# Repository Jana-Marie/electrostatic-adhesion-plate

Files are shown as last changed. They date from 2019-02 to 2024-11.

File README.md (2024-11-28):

# electrostatic-adhesion-plate

#### Motivation

The motivation behind this project is that I wanted to test how strong [electro-adhesion](https://en.wikipedia.org/wiki/Electroadhesion) really is and what clamping force I can get myself with it. Since PCBs are very inexpensive nowadays, the choice fell on electrodes directly on a circuit board. In the first version (100x100mm) the electrode gap is not yet optimal and there are points where corona discharges are likely, this is fixed in the second version (DinA5).

A batch (50pcs) of the seccond version is about to be ordered by me.

#### Design

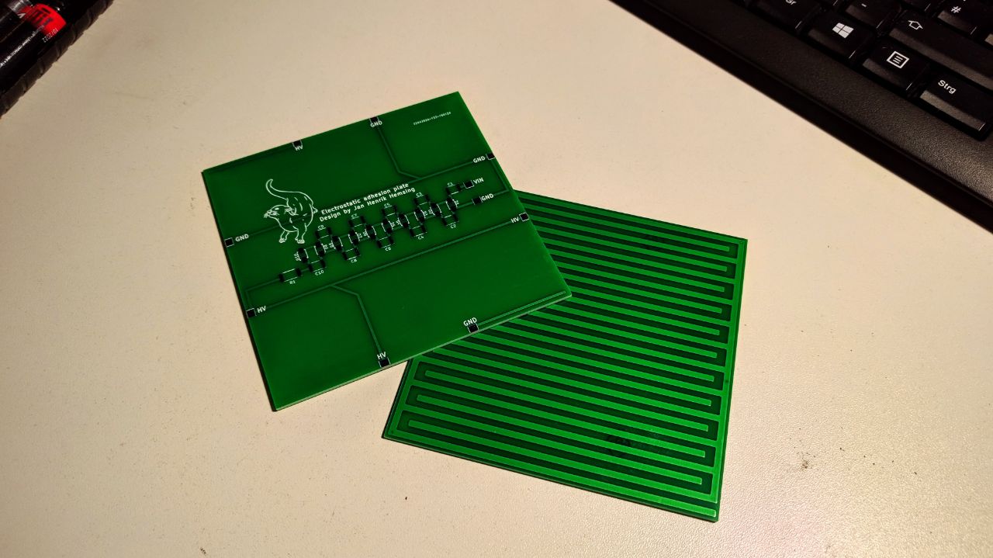
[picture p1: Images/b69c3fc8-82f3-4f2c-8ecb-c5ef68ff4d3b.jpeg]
Design


The boards were designed so that they can be connected to larger printed circuit boards (electrically) using solder connections. This makes it possible to build relatively large electroadhesive surfaces with relatively inexpensive printed circuit boards.

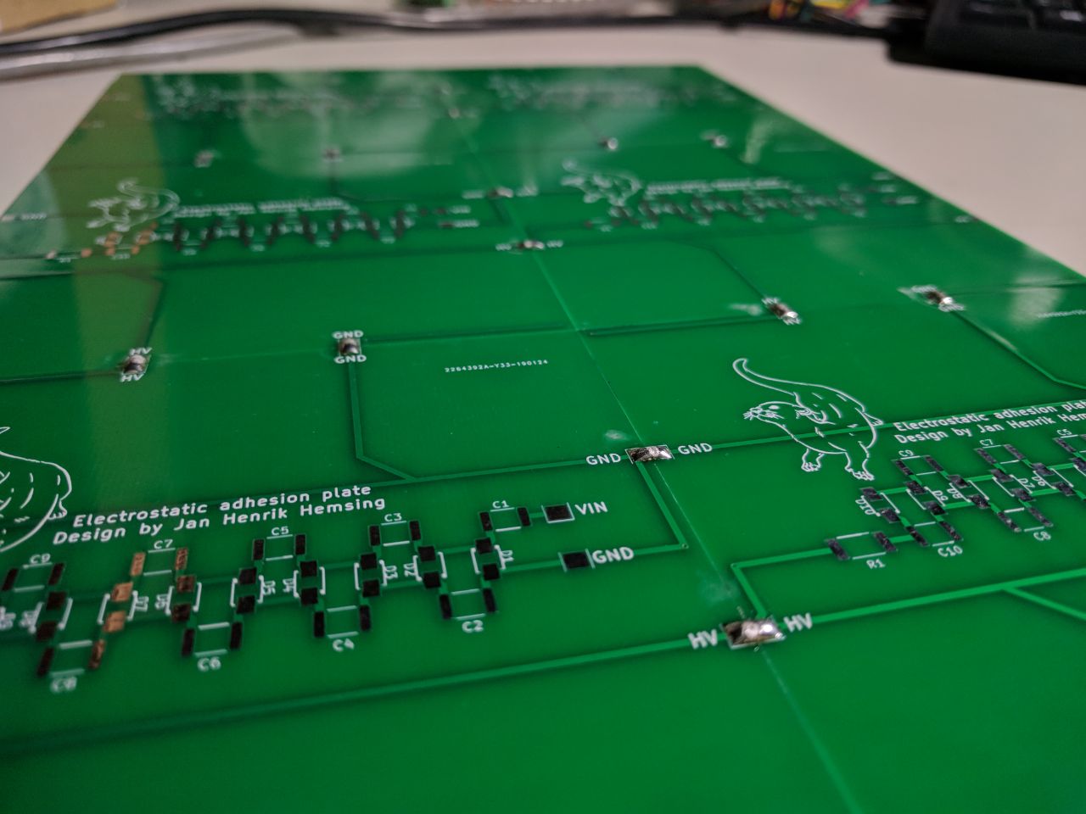
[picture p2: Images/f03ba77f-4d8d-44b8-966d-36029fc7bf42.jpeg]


The surface of each PCB or the whole panel should be coated with a high voltage isolator, as the soldermask does not withstand high voltage very well. Kapton is a suitable material as its dielectric strength is about 7.6kV/25µm, unfortunately it is difficult to apply.
Another solution which is being tested is PlastiDip. PlastiDip has a much lower dielectric strength 1.6kV/25µm, so it has to be applied thicker. The advantage here is the rubber-like surface which generates a higher shear force due to its friction.

https://github.com/user-attachments/assets/e9a8f286-f70a-4371-af7a-df20809293cf

https://github.com/user-attachments/assets/fc1b60f5-51d2-4803-b8a3-286581b4381b

The electrode voltage should be between 500V and 5kV DC (depending on the design), whereby a higher voltage means a higher holding force. This voltage can be obtained from any cheap DC high voltage source (e.g. a bug zapper) or from a low AC voltage source (Please do not use direct mains voltage). The AC voltage can be multiplied and rectified by the Cockcroft Walton voltage multiplier on the back of the PCB.

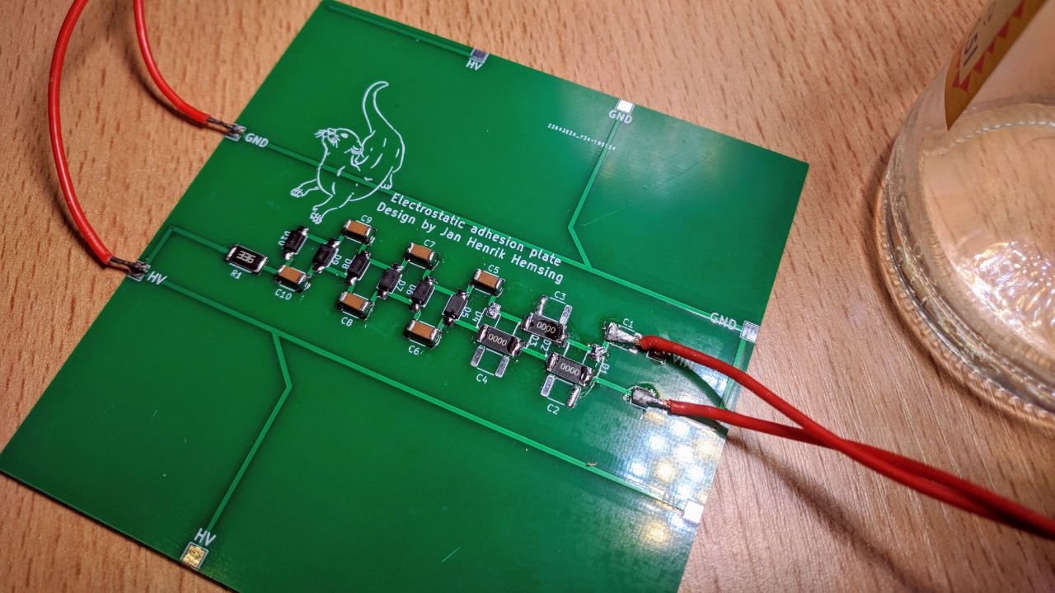
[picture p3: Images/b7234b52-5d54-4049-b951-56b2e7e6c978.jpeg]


___

## [100mm * 100mm](100100mm/)

| **Parameter** | **Value** |
| --- |:---:|
| Electrode Voltage | 500V-2000V |
| Electrode Voltage*| 500V-3000V |
| *Without extra coating (silkscreen)*|
| shearing force | 9N @1.4kV |
| shearing force cm²| 90mN/cm² @1.2kV|
| adhesive force | ** |
| **PlastiDip Coating** |
| shearing force | 4N @1.4kV |
| shearing force cm²| 40mN/cm² @1.2kV|
| adhesive force | ** |
| **Kapton Coating** |
| shearing force | 2.5N @1.4kV |
| shearing force cm²| 25mN/cm² @1.2kV|
| adhesive force | ** |

\* With Insulation

\** TBD

#### [Demo Video](https://twitter.com/_Jana_Marie/status/1094664006059593729)

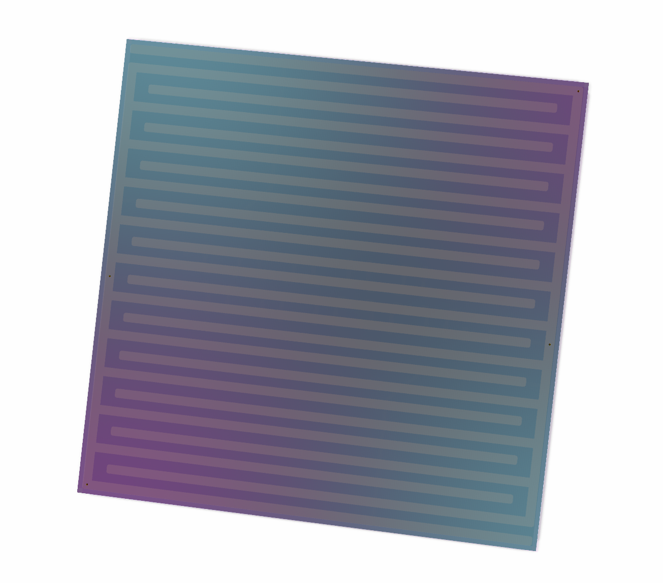
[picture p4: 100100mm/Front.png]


___

## [DIN A5](DINA5)

| **Parameter** | **Value** |
| --- |:---:|
| Electrode Voltage | 500V-2000V |
| Electrode Voltage*| 500V-5000V |
| shearing force | ** |
| adhesive force | ** |

\* With Insulation

\** TBD

#### Changes to V1 (100100mm)

 * Size is now 148*210mm (DinA5)
 * Electrode width and distance are optimized
 * M3 threads where added
 * Sharp edges where removed

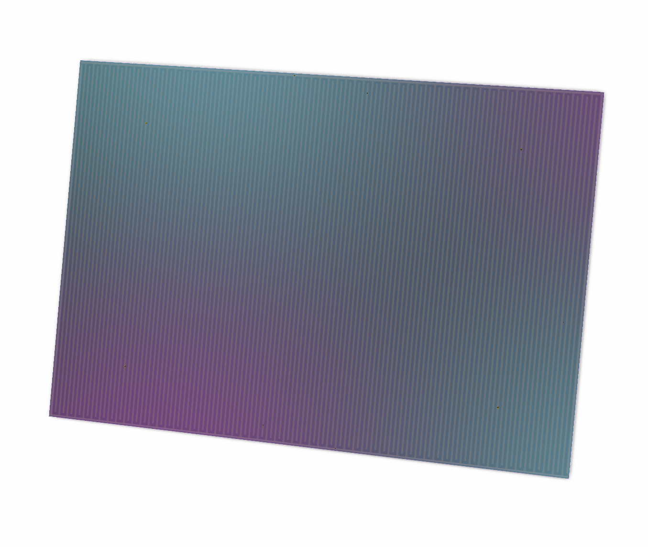
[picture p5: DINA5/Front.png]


### [5050mm](DINA5)

| **Parameter** | **Value** |
| --- |:---:|
| Electrode Voltage | 500V-2000V |
| Electrode Voltage*| 500V-5000V |
| shearing force | 600mN |
| shearing force cm²| 6mN/cm² @1.2kV|
| adhesive force | ** |

\* With Insulation

\** TBD

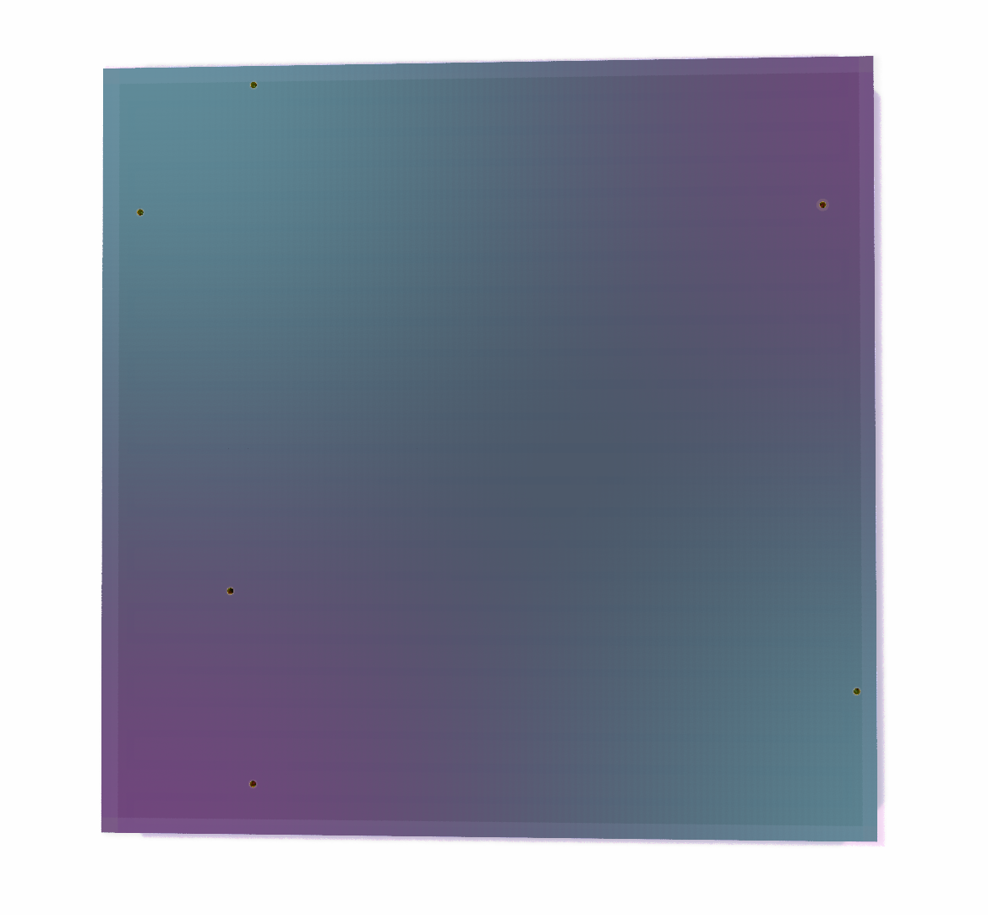
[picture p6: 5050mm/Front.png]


### License

Copyright Jana Marie Hemsing 2022.

This source describes Open Hardware and is licensed under the CERN-OHL-S v2.

You may redistribute and modify this source and make products using it under
the terms of the CERN-OHL-S v2 (https://ohwr.org/cern_ohl_s_v2.txt).

This source is distributed WITHOUT ANY EXPRESS OR IMPLIED WARRANTY,
INCLUDING OF MERCHANTABILITY, SATISFACTORY QUALITY AND FITNESS FOR A
PARTICULAR PURPOSE. Please see the CERN-OHL-S v2 for applicable conditions.

Source location: https://github.com/Jana-Marie/electrostatic-adhesion-plate

As per CERN-OHL-S v2 section 4, should You produce hardware based on this
source, You must where practicable maintain the Source Location visible
on the external case of the Gizmo or other products you make using this
source.

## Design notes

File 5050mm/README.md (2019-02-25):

# electrostatic-adhesion-plate

Frontview
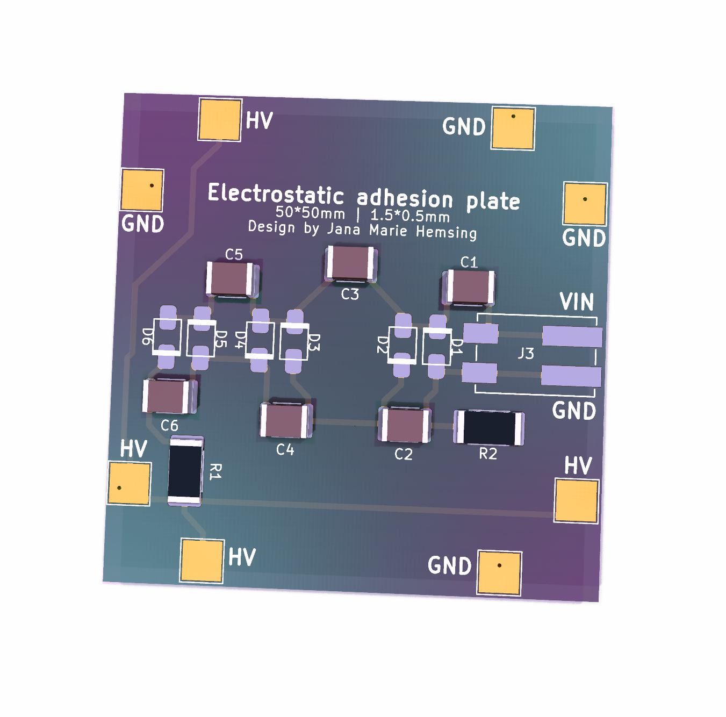
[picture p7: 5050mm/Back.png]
Backview


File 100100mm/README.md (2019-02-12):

# electrostatic-adhesion-plate

Frontview
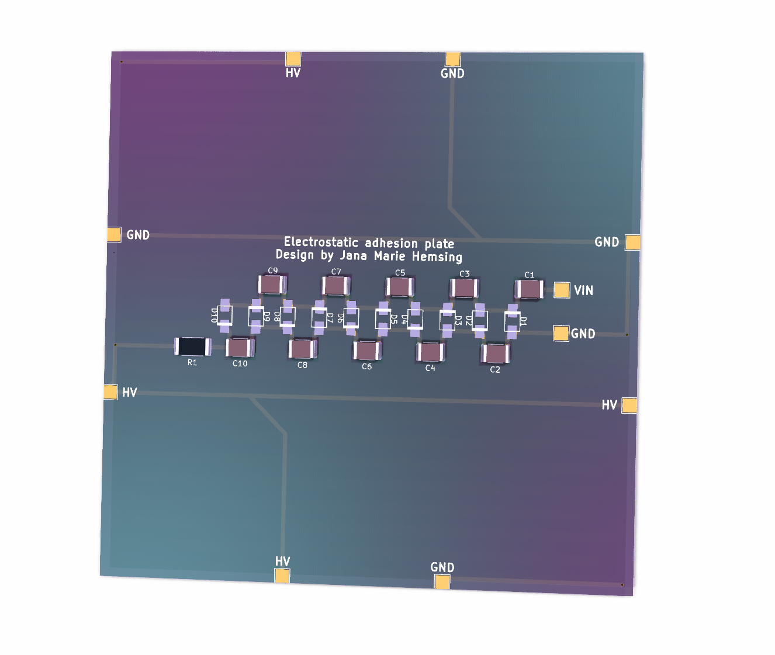
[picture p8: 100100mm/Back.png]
Backview


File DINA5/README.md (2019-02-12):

# electrostatic-adhesion-plate

Frontview
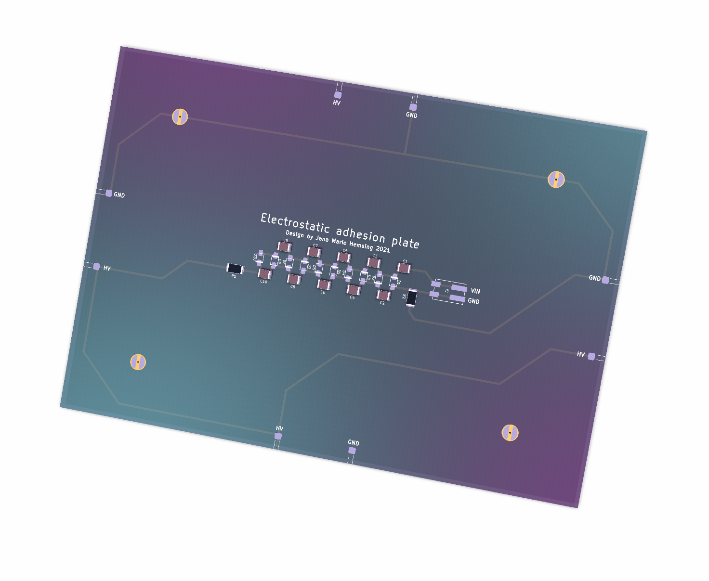
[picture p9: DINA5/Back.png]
Backview

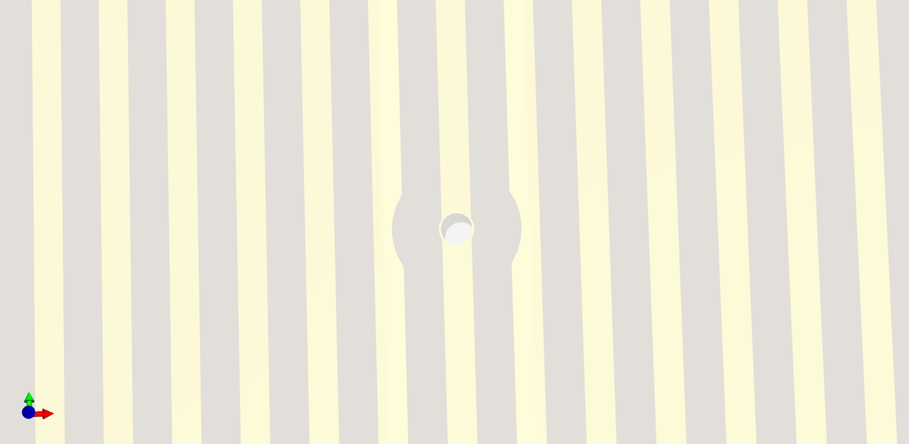
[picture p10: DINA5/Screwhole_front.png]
Hole


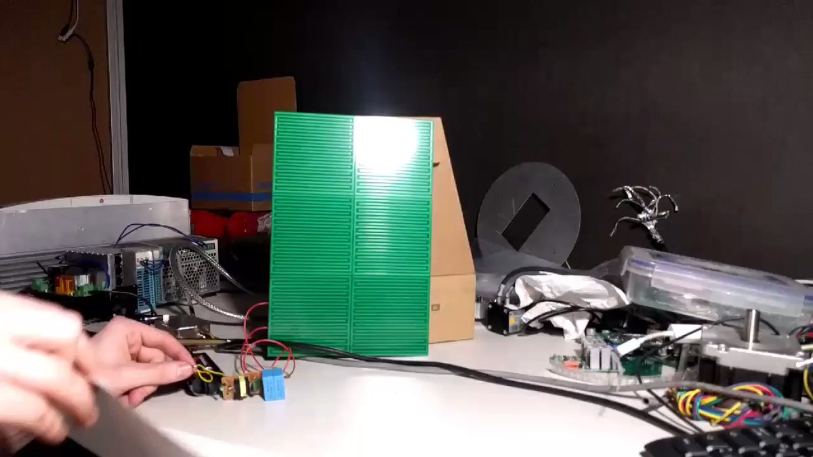
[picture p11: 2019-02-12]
Images/thumb.jpg

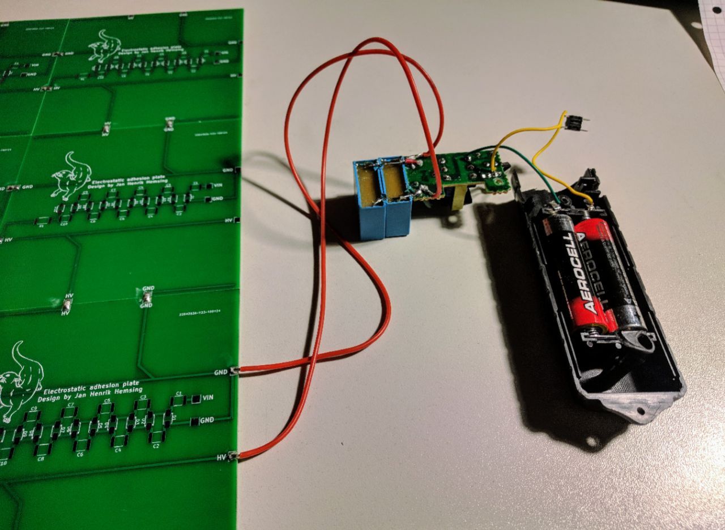
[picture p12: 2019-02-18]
Images/ef6641a6-9924-47fd-a86e-b7c47ad1484e.jpeg

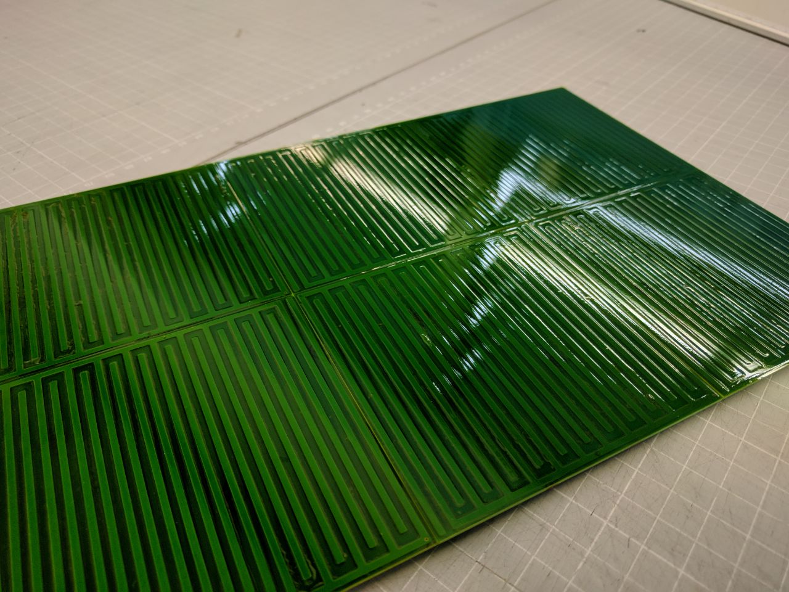
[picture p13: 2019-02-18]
Images/be6c334a-8df6-4404-90c8-2e3c69afee05.jpeg

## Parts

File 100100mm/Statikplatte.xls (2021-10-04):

Comment | Designator | Footprint | LCSC
1n | C1,C2,C3,C4,C5,C6,C7,C8,C9,C10 | Capacitor_SMD:C_1812_4532Metric
SS34 | D1,D2,D3,D4,D5,D6,D7,D8,D9,D10 | otter:SMAF
VIN | J1 | TestPoint:TestPoint_Pad_2.5x2.5mm
GND | J2,J3,J4,J5,J6 | TestPoint:TestPoint_Pad_2.5x2.5mm
HV | J8,J7,J9,J10 | TestPoint:TestPoint_Pad_2.5x2.5mm
33M | R1 | Resistor_SMD:R_2512_6332Metric

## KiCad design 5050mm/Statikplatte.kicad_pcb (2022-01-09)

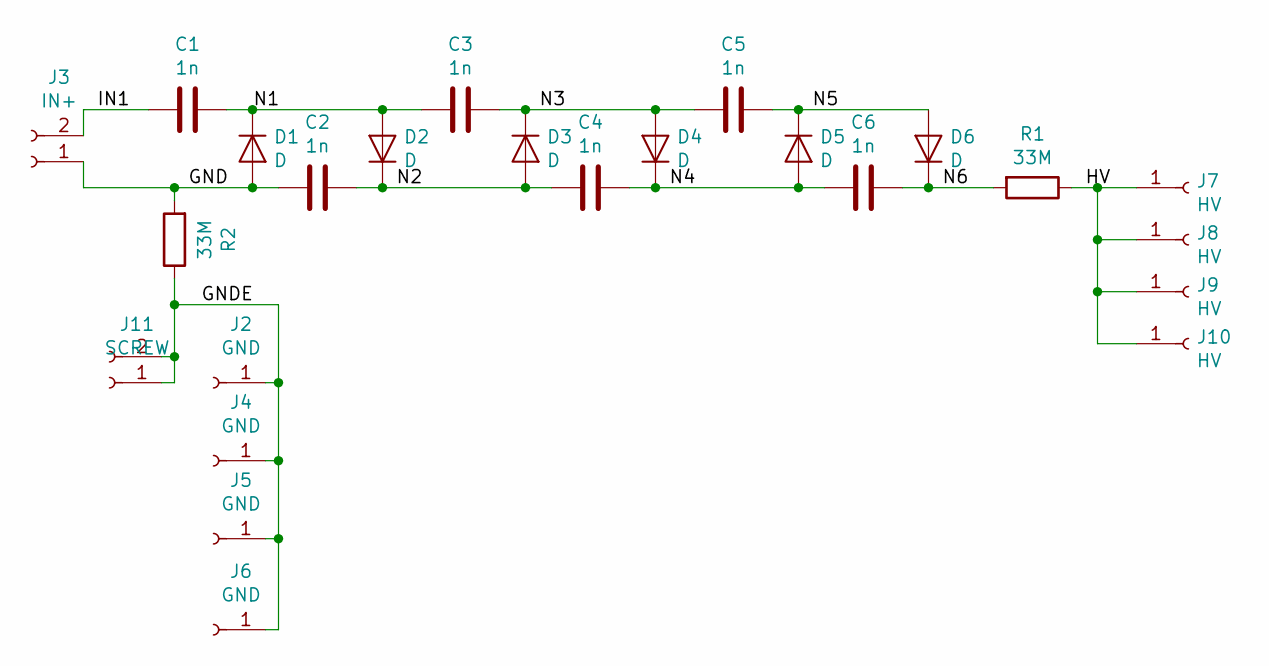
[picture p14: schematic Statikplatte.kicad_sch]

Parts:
C1, C2, C3, C4, C5, C6: 1n; C_1812_4532Metric
D1, D2, D3, D4, D5, D6: D; SMAF
J2, J4, J5, J6: GND; TestPoint_Pad_4.0x4.0mm
J3: IN+; LED_Connector
J7, J8, J9, J10: HV; TestPoint_Pad_4.0x4.0mm
J11: SCREW; M3_Screw
R1, R2: 33M; R_2512_6332Metric

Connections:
/GND: C2.2, D1.2 (A), J3.1, R2.2
/GNDE: J2.1, J4.1, J5.1, J6.1, J11.1, J11.2, R2.1
/HV: J7.1, J8.1, J9.1, J10.1, R1.1
/IN1: C1.2, J3.2
/N1: C1.1, C3.2, D1.1 (K), D2.2 (A)
/N2: C2.1, C4.2, D2.1 (K), D3.2 (A)
/N3: C3.1, C5.2, D3.1 (K), D4.2 (A)
/N4: C4.1, C6.2, D4.1 (K), D5.2 (A)
/N5: C5.1, D5.1 (K), D6.2 (A)
/N6: C6.1, D6.1 (K), R1.2

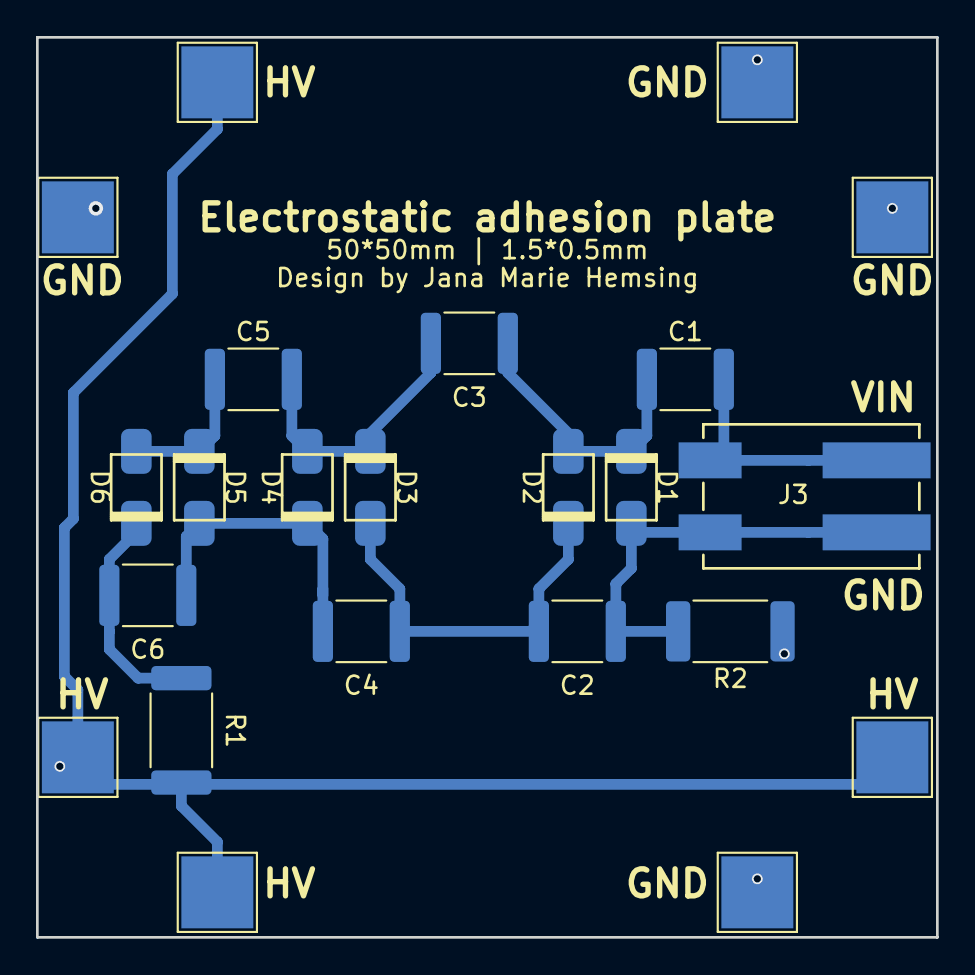
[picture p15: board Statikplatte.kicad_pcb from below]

Board: 4 copper layers, 50.0 x 50.0 mm, 23 parts (23 on the bottom side), 10 nets.

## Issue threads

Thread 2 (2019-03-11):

Inner traces

Immortalin, 2019-03-11:
Is it possible to use a multilayer board design with only inner traces and skip the Kapton/PlastiDip step entirely?

Jan--Henrik, 2019-03-11:
Probably, I recently ordered such a design. It should be delivered in a few days. I can tell you more then :)

lalalandrus, 2019-03-12:
dave @ eeevblog did a video on a commercial whiteboard. it seems they used a wave pattern to promote interaction with the + and - regions. perhaps a suggestion is to meander the traces for the + and the - to improve the adhesion but not so close that it gets nullified.

Jan--Henrik, 2019-03-12:
@lalalandrus I've looked into that topic, there are several papers out there exploring electrostatic adhesion for grippers. Most papers suggested that a electrode pattern like I use it generates the highest adhesion force. However, this pattern is hard to produce, if you have to glue it, such a meander pattern is much easier to apply.

Gray-Stone, 2019-04-14:
I wonder if the trace width and spacing makes any difference, and what ratio would be best?

Jan--Henrik, 2019-04-25:
Hey @Gray-Stone, sorry for the late reply. Indeed it does, a ration of 2:1 (Trace 2 : width 1) seems to be a good start. As for the actual width, 1-3mm space to 3-9mm trace seems to work good. (All informations obtained from papers, I haven't found the best ratio/size by myself yet) :)

Immortalin, 2019-08-07:
@Jan--Henrik so how did the inner traces ones go?

Immortalin, 2019-08-07:
Also is it possible to round out the corners a bit more just in case of corona?

Immortalin, 2019-08-07:
Also, for covering over the solders at the back, are you just using Kapton tape?

Jan--Henrik, 2019-08-07:
> @Jan--Henrik so how did the inner traces ones fare?

Hey, I've ordered and tested serveral different 4-layer PCBs. There is a adhesion force but it is much weaker then with direct copper on a 2-layer board. :/

> Also is it possible to round out the corners a bit more just in case of corona?

This project is a OSHW project, so you can do that yourself if you want :) However I haven't noticed any corona yet, so it is probably not needed.

> Also, for covering over the solders at the back, are you just using Kapton tape?

Yep, it is quite complicated to apply, using water+soap to prevent air bubbles worked very well. Make sure to bake everything afterwards (~60°C ~2h) to remove any moisture. PlastiDip (spray-able rubber) also worked, but has a weaker dielectric strength.

Immortalin, 2019-08-07:
I am considering making an even lower budget version with copper tape and paper and lamination.

Gray-Stone, 2019-10-28:
> I am considering making an even lower budget version with copper tape and paper and lamination.

I've tryied this. Copper tape on a hardboard (which is dense cardboard), sucks up at least a paper with just 8 stripes of 1inch wide copper tape. (about 1Kv)

Closed 2019-08-07.

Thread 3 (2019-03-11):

Castellation/Jigsaw

Immortalin, 2019-03-11:
Join together like lego

Immortalin, 2019-03-12:
Like this: https://electronics.stackexchange.com/questions/35625/soldering-pcbs-directly-together

Jan--Henrik, 2019-03-12:
https://github.com/Jan--Henrik/electrostatic-adhesion-plate/raw/master/Images/f03ba77f-4d8d-44b8-966d-36029fc7bf42.jpeg
You can do that already with the current PCB, but a SMD lego connector sounds very nice :D

Immortalin, 2019-03-12:
Won't a castellate wavy edges offer better grip than a perfectly smooth one?

Jan--Henrik, 2019-03-12:
It will, but it also will expose the high voltage to the front of the PCB, I want to avoid that.

Closed 2019-03-12.

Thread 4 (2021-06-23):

Making a wall more static-y?

philCryoport, 2021-06-23:
Hi there, I just introduced [SlickyNotes](https://www.youtube.com/watch?v=skl6uBIxNMI) to my company -- where static electricity causes Post-It-like squares to attach to a wall or glass and be able to be moved around very easily.  They're great for visualizations of things.

The problem I've discovered is that the wall I'm using doesn't seem to have much static electricity.  HackADay had a post on this project.

If I was to say glue one of these plates to the middle of my wall and turn it on, would it pass the static electricity across the entire wall surface? (there would probably be attenuation proportional to distance)

Jana-Marie, 2021-10-04:
Hey, I am afraid, that It will not. You would need to build a wall out of adhesion plates

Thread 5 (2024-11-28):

Video demo links broken

pzl, 2024-11-28:
Came across this project and was interested to see it in action!

However the demo video links in the readme are twitter links that appear to no longer work.

Do you still have the demo clips? Can they be reuploaded somewhere else?

Jana-Marie, 2024-11-28:
Sure, here!

https://github.com/user-attachments/assets/e9a8f286-f70a-4371-af7a-df20809293cf

https://github.com/user-attachments/assets/fc1b60f5-51d2-4803-b8a3-286581b4381b

pzl, 2024-11-28:
Thank you!!

this helped put an intuitive feel into how much grab there was, though I know you documented the numbers here.

Closed 2024-11-28.

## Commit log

2019-01-23 added KiCAD files
    [Statikplatte.kicad_pcb, Statikplatte.sch]
2019-01-23 added gerber
    [Statikplatte-B.Cu.gbl, Statikplatte-B.Mask.gbs, Statikplatte-B.Paste.gbp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]
2019-02-11 moved files and created DINA5 sized adhesion plate
    [Statikplatte-B.Cu.gbl, Statikplatte-B.Mask.gbs, Statikplatte-B.Paste.gbp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]
2019-02-11 added DINA5 files
    [Statikplatte.kicad_pcb, _saved_Statikplatte.sch]
2019-02-11 removed double folders
    [Statikplatte-B.Cu.gbl, Statikplatte-B.Mask.gbs, Statikplatte-B.Paste.gbp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]
2019-02-11 added screws
    [Statikplatte.kicad_pcb, Statikplatte.sch]
2019-02-11 updated schematic
    [_saved_Statikplatte.sch]
2019-02-12 updated PCB
    [Statikplatte.kicad_pcb]
2019-02-12 added Otter
    [Statikplatte.kicad_pcb]
2019-02-12 moved screws and added contributor
    [Statikplatte.kicad_pcb]
2019-02-13 added resistor to gnd
    [Statikplatte.kicad_pcb, Statikplatte.sch]
2019-02-22 added negative kaskade
    [Statikplatte.kicad_pcb, Statikplatte.sch]
2019-02-24 went back to one voltage multiplier
    [Statikplatte.kicad_pcb, Statikplatte.sch]
2019-02-24 updated PCB and Gerber
    [Statikplatte-B.Cu.gbl, Statikplatte-B.Mask.gbs, Statikplatte-B.Paste.gbp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]
2019-02-25 added 50*50mm 4 layer test pcb
    [Statikplatte-B.Cu.gbl, Statikplatte-B.Mask.gbs, Statikplatte-B.Paste.gbp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]
2021-10-04 updated design
    [Statikplatte.kicad_pcb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]
2021-10-04 updated boards
    [Statikplatte-B.Cu.gbl, Statikplatte-B.Mask.gbs, Statikplatte-B.Paste.gbp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]
2021-10-04 added images
    [Statikplatte.kicad_pcb]
2022-01-09 updated to KICAD 6
    [Statikplatte-B.Cu.gbl, Statikplatte-B.Mask.gbs, Statikplatte-B.Paste.gbp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]
